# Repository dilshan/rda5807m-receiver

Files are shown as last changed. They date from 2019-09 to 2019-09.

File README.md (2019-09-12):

# FM stereo radio receiver with RDS

This tuner circuit is a quick prototype which I build to test the *RDA5807M* FM radio tuner IC. *RDA5807M* is a single-chip tuner IC with RDS and MPX decoder, and it equipped with I2C interface for control. 

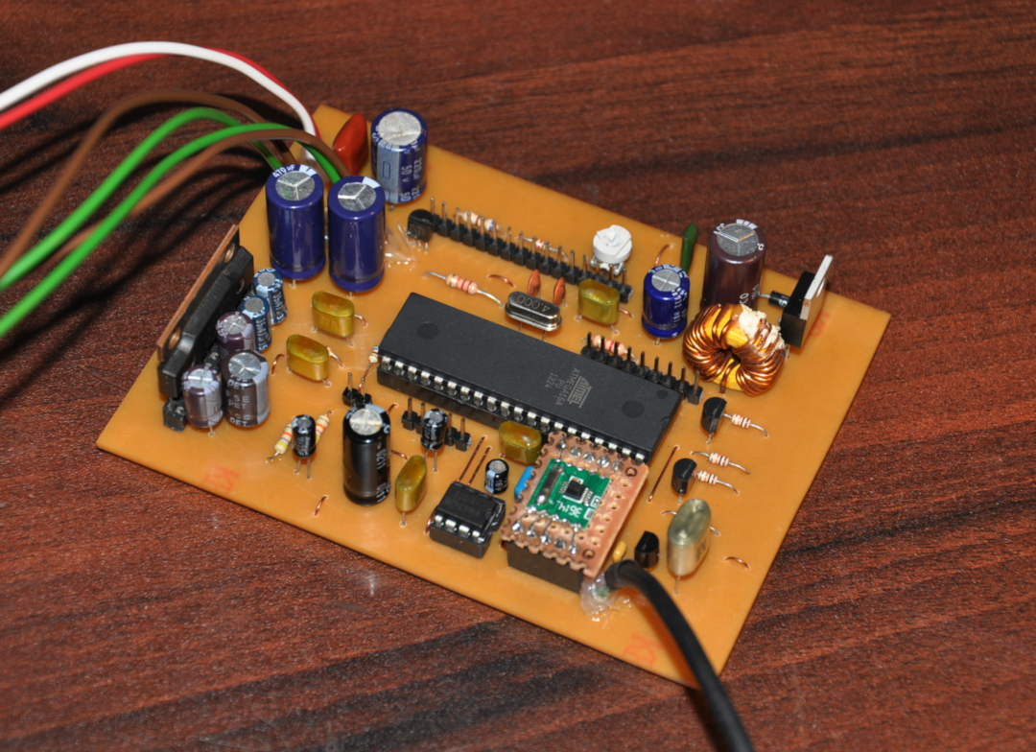
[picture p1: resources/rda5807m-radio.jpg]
Prototype version of the RDA5807M receiver


This receiver builds around Atmel's *ATmega16A* 8-bit MCU. The output stage of this design consists of *AN7147N*, 2×5.3W audio power amplifier. 

Based on the specifications of the switching-regulator and power amplifier, this circuit can drive between 9V to 20V DC input. The most recommended working voltage for this receiver is 12V.

As mentioned above this design is a quick prototype to test the features of *RDA5807M* tuner. Most of the parameters of this tuner are hardcoded in the firmware and not exposed in UI. 

-------------------------------------------------------------------------------------------------------------------------

The firmware source codes of this project are released under the terms of the [MIT license](https://github.com/dilshan/rda5807m-receiver/blob/master/LICENSE). All the design files and schematics are released under the terms of the [Creative Commons - Attribution 4.0 International license](https://creativecommons.org/licenses/by/4.0/).

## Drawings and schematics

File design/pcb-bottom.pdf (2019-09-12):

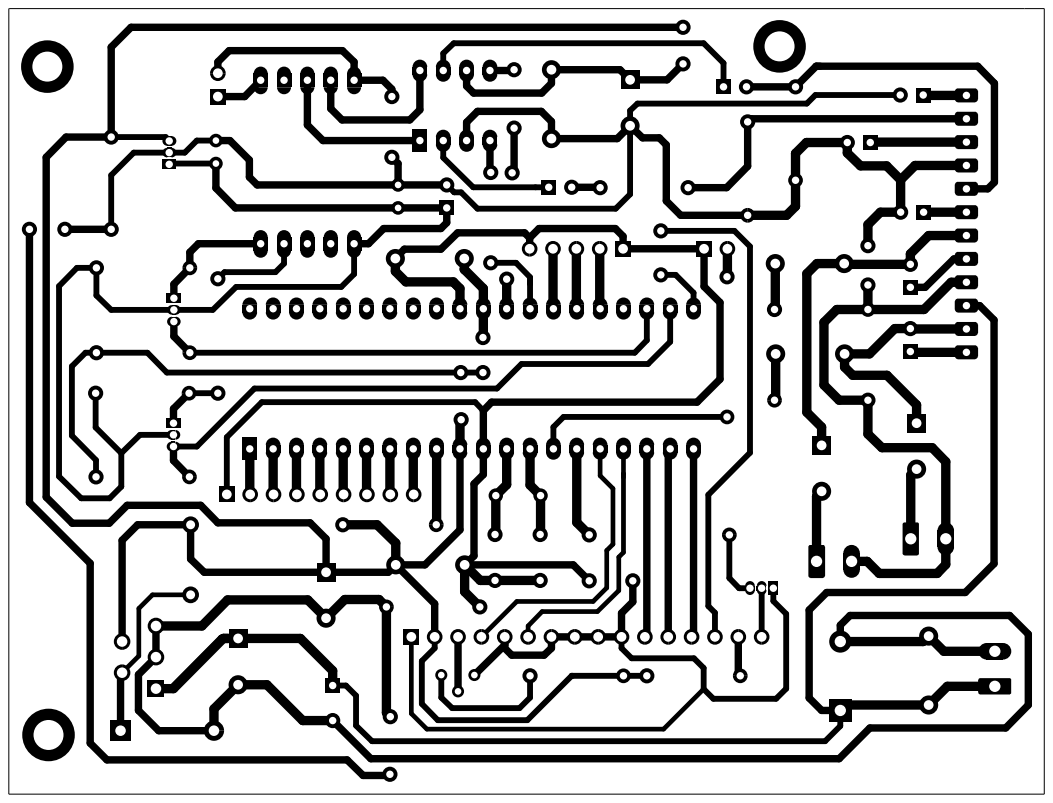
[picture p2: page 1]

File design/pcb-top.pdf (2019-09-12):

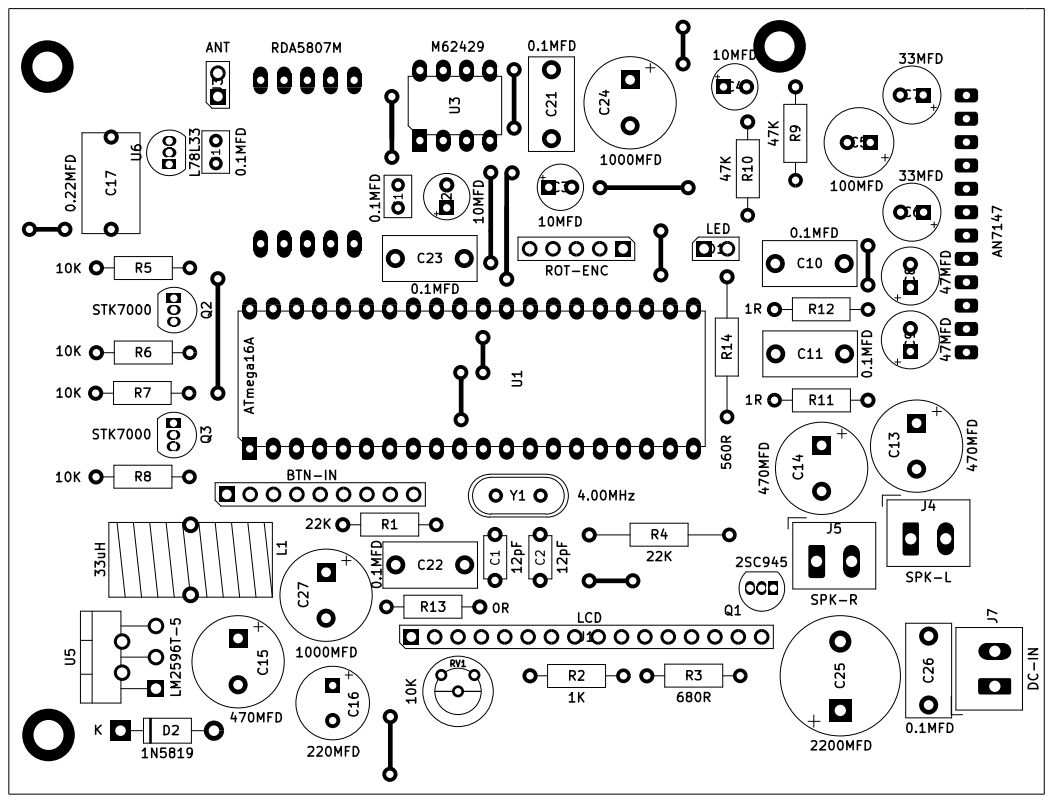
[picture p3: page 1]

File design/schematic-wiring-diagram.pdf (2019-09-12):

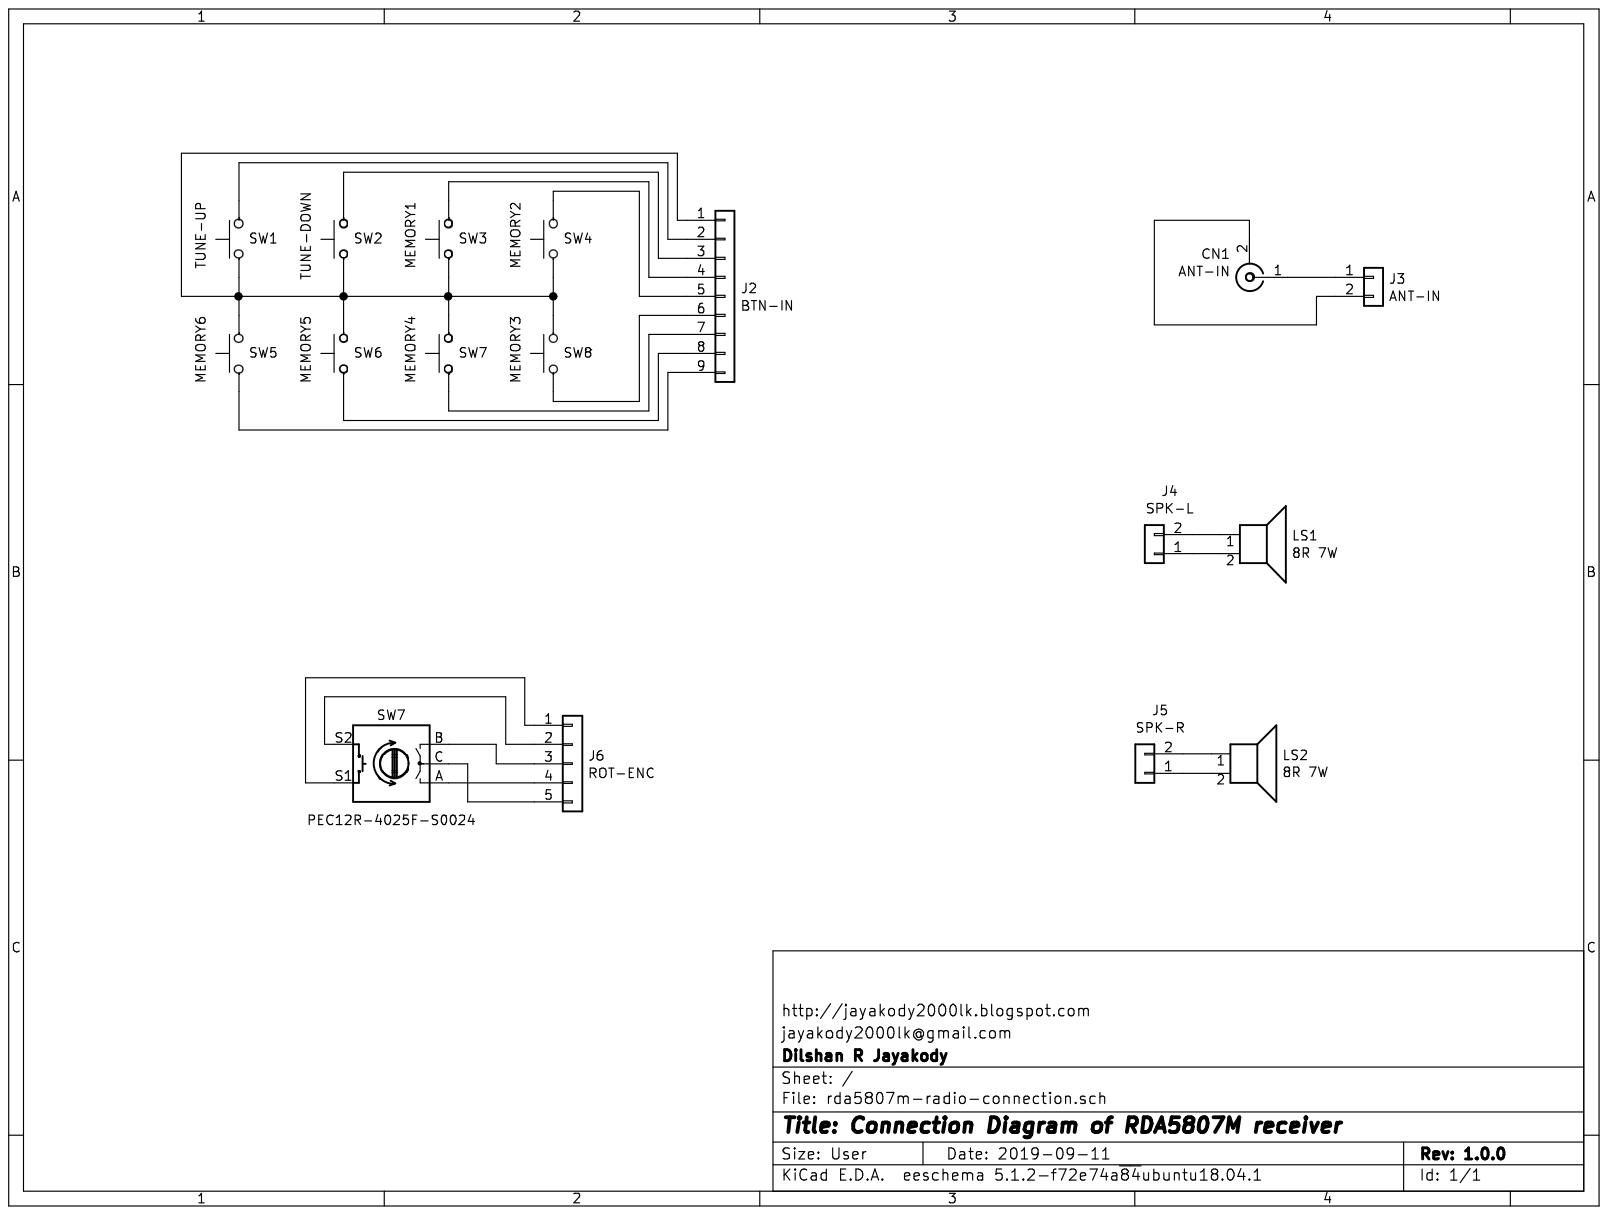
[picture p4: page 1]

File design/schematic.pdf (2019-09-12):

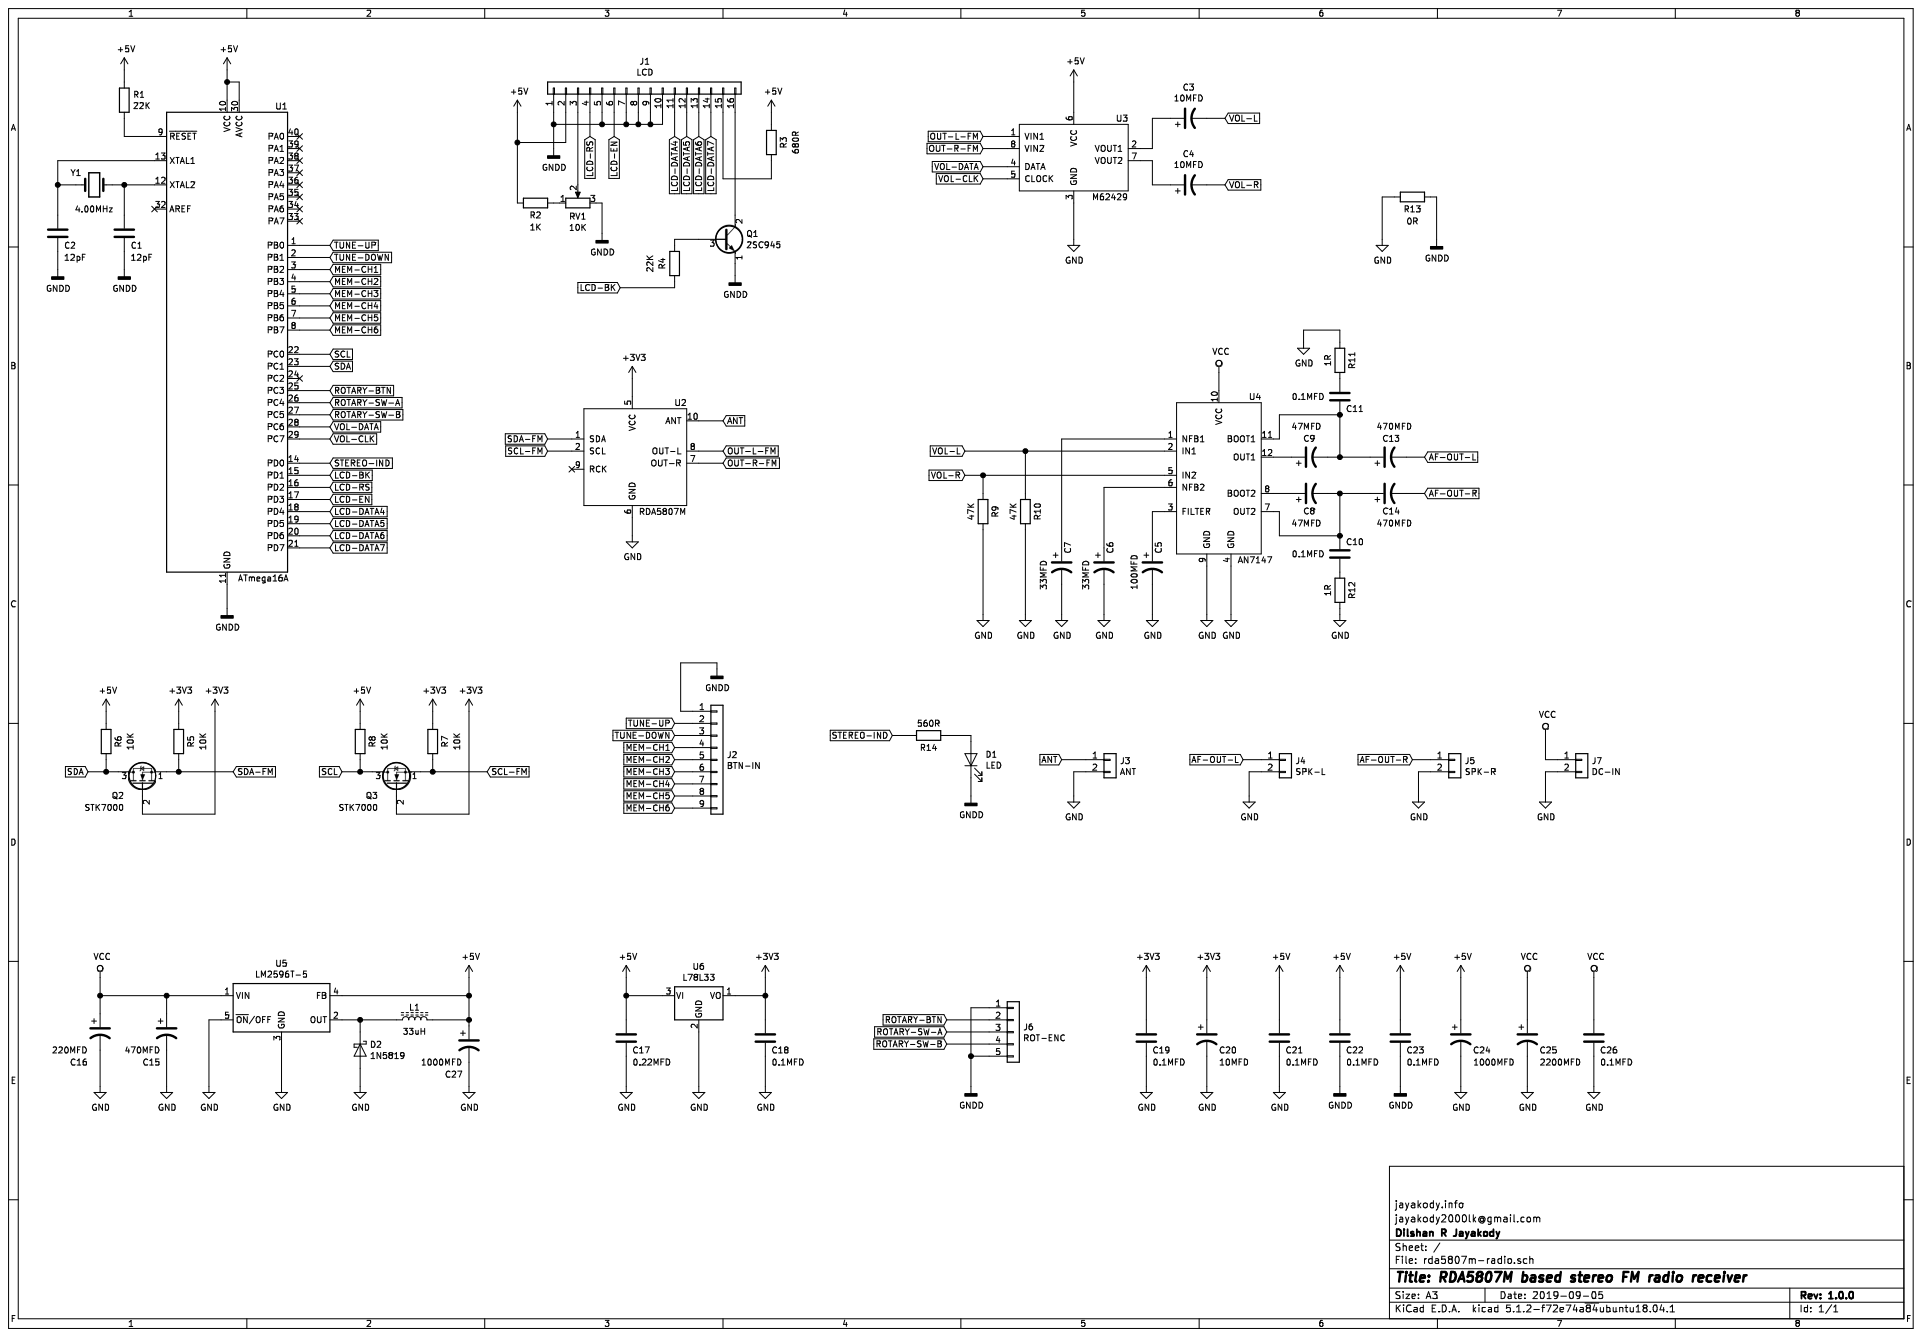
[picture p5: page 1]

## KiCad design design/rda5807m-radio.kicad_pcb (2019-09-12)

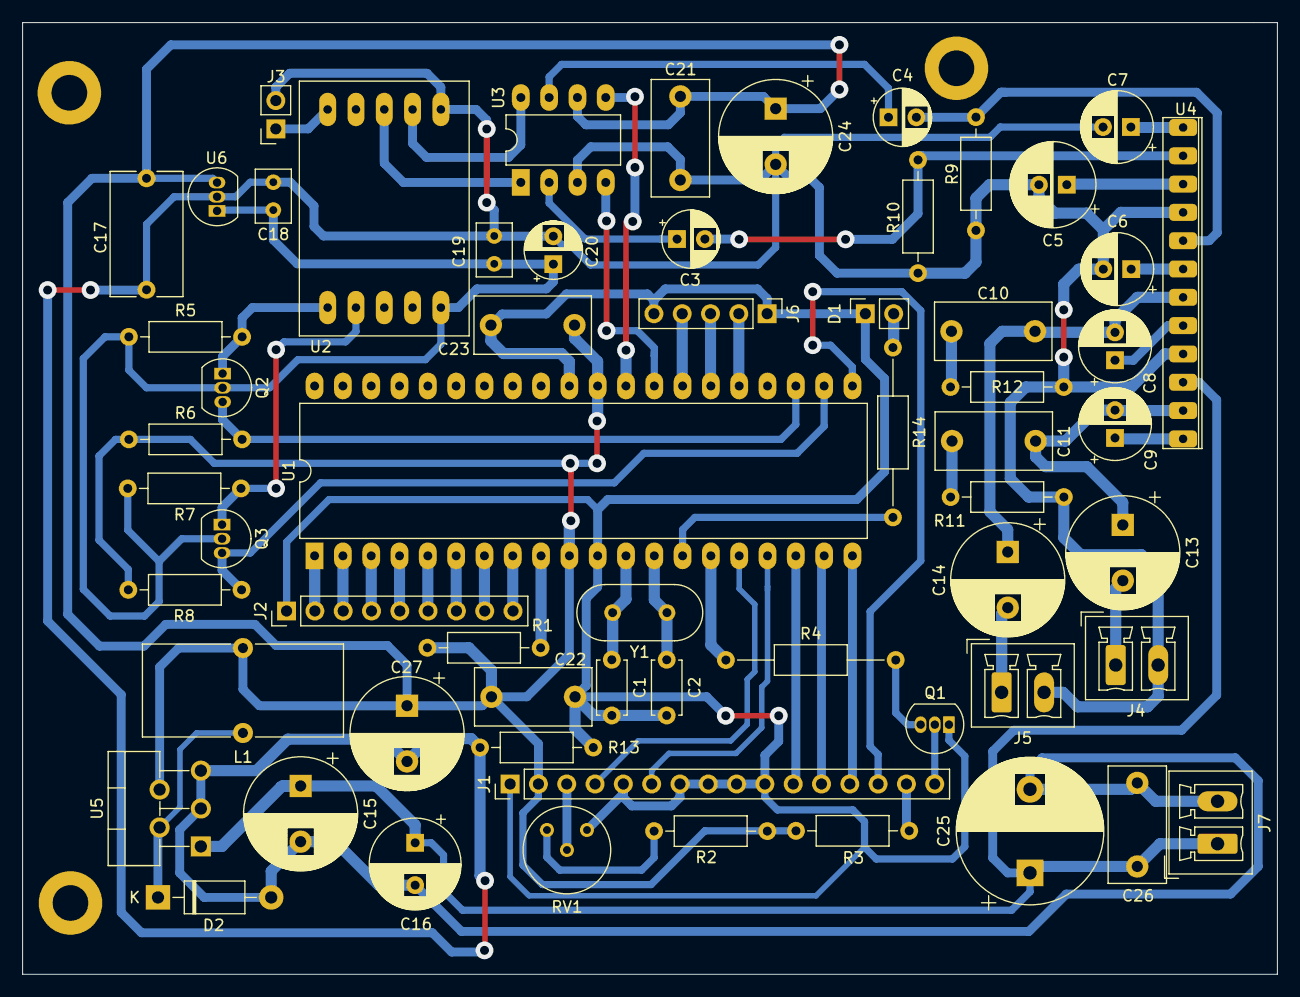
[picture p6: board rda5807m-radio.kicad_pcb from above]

Board: 2 copper layers, 112.6 x 85.4 mm, 64 parts (0 on the bottom side), 58 nets.

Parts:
 : MountingHole_3.2mm_M3_ISO7380_Pad
 #2,  #3: MountingHole_3.2mm_M3_ISO7380_Pad
C1, C2: 12pF; C_Disc_D4.7mm_W2.5mm_P5.00mm
C3, C4, C20: 10MFD; CP_Radial_D5.0mm_P2.50mm
C5: 100MFD; CP_Radial_D7.5mm_P2.50mm
C6, C7: 33MFD; CP_Radial_D6.3mm_P2.50mm
C8, C9: 47MFD; CP_Radial_D6.3mm_P2.50mm
C10, C11, C21, C22, C23, C26: 0.1MFD; C_Rect_L10.3mm_W5.0mm_P7.50mm_MKS4
C13, C14, C15: 470MFD; CP_Radial_D10.0mm_P5.00mm
C16: 220MFD; CP_Radial_D8.0mm_P3.80mm
C17: 0.22MFD; C_Rect_L11.0mm_W6.3mm_P10.00mm_MKT
C18, C19: 0.1MFD; C_Rect_L4.6mm_W3.0mm_P2.50mm_MKS02_FKP02
C24, C27: 1000MFD; CP_Radial_D10.0mm_P5.00mm
C25: 2200MFD; CP_Radial_D13.0mm_P7.50mm
D1: LED; PinSocket_1x02_P2.54mm_Vertical
D2: 1N5819; D_DO-41_SOD81_P10.16mm_Horizontal
J1: LCD; PinHeader_1x16_P2.54mm_Vertical
J2: BTN-IN; PinHeader_1x09_P2.54mm_Vertical
J3: ANT; PinSocket_1x02_P2.54mm_Vertical
J4: SPK-L; PhoenixContact_MCV_1,5_2-G-3.81_1x02_P3.81mm_Vertical
J5: SPK-R; PhoenixContact_MCV_1,5_2-G-3.81_1x02_P3.81mm_Vertical
J6: ROT-ENC; PinHeader_1x05_P2.54mm_Vertical
J7: DC-IN; PhoenixContact_MCV_1,5_2-G-3.81_1x02_P3.81mm_Vertical
L1: 33uH; L_Toroid_Vertical_L17.8mm_W8.1mm_P7.62mm_Bourns_5700
Q1: 2SC945; TO-92_Inline
Q2, Q3: STK7000; TO-92_Inline
R1: 22K; R_Axial_DIN0207_L6.3mm_D2.5mm_P10.16mm_Horizontal
R2: 1K; R_Axial_DIN0207_L6.3mm_D2.5mm_P10.16mm_Horizontal
R3: 680R; R_Axial_DIN0207_L6.3mm_D2.5mm_P10.16mm_Horizontal
R4: 22K; R_Axial_DIN0207_L6.3mm_D2.5mm_P15.24mm_Horizontal
R5, R6, R7, R8: 10K; R_Axial_DIN0207_L6.3mm_D2.5mm_P10.16mm_Horizontal
R9, R10: 47K; R_Axial_DIN0207_L6.3mm_D2.5mm_P10.16mm_Horizontal
R11, R12: 1R; R_Axial_DIN0207_L6.3mm_D2.5mm_P10.16mm_Horizontal
R13: 0R; R_Axial_DIN0207_L6.3mm_D2.5mm_P10.16mm_Horizontal
R14: 560R; R_Axial_DIN0207_L6.3mm_D2.5mm_P15.24mm_Horizontal
RV1: 10K; Potentiometer_Bourns_3339H_Vertical
U1: ATmega16A; DIP-40_W15.24mm_LongPads
U2: RDA5807M; RDA5807M-MODULE
U3: M62429; DIP-8_W7.62mm_LongPads
U4: AN7147; SIP-12-2P
U5: LM2596T-5; TO-220-5_P3.4x3.7mm_StaggerOdd_Lead3.8mm_Vertical
U6: L78L33; TO-92_Inline
Y1: 4.00MHz; Crystal_HC49-U_Vertical

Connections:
+3V3: C18.1, C19.1, C20.1, Q2.2, Q3.2, R5.1, R7.1, U2.5, U6.1
+5V: C17.1, C21.1, C22.1, C23.1, C24.1, C27.1, J1.2, L1.2, R1.1, R2.2, R3.1, R6.1, R8.1, U1.10, U1.30, U3.6, U5.4, U6.3
AF-OUT-L: C13.2, J4.1
AF-OUT-R: C14.2, J5.1
ANT: J3.1, U2.10
GND: C5.2, C6.2, C7.2, C15.2, C16.2, C17.2, C18.2, C19.2, C20.2, C21.2, C24.2, C25.2, C26.2, C27.2, D2.2, J3.2, J4.2, J5.2, J7.2, R9.2, R10.2, R11.1, R12.2, R13.2, U2.6, U3.3, U4.4, U4.9, U5.3, U5.5, U6.2
GNDD: C1.2, C2.2, C22.2, C23.2, D1.1, J1.1, J1.5, J1.7, J1.8, J1.9, J1.10, J2.1, J6.1, J6.5, Q1.1, R13.1, RV1.3, U1.11, U1.31
LCD-BK: R4.1, U1.15
LCD-DATA4: J1.11, U1.18
LCD-DATA5: J1.12, U1.19
LCD-DATA6: J1.13, U1.20
LCD-DATA7: J1.14, U1.21
LCD-EN: J1.6, U1.17
LCD-RS: J1.4, U1.16
MEM-CH1: J2.4, U1.3
MEM-CH2: J2.5, U1.4
MEM-CH3: J2.6, U1.5
MEM-CH4: J2.7, U1.6
MEM-CH5: J2.8, U1.7
MEM-CH6: J2.9, U1.8
unnamed: C1.1, U1.12, Y1.2
unnamed: C2.1, U1.13, Y1.1
unnamed: C3.1, U3.2
unnamed: C4.1, U3.7
unnamed: C5.1, U4.3
unnamed: C6.1, U4.6
unnamed: C7.1, U4.1
unnamed: C8.1, U4.8
unnamed: C9.1, U4.12
unnamed: C8.2, C10.1, C14.1, U4.7
unnamed: C10.2, R12.1
unnamed: C11.1, R11.2
unnamed: C9.2, C11.2, C13.1, U4.11
unnamed: D1.2, R14.1
unnamed: D2.1, L1.1, U5.2
unnamed: J1.3, RV1.2
unnamed: J1.15, R3.2
unnamed: J1.16, Q1.2
unnamed: Q1.3, R4.2
unnamed: R1.2, U1.9
unnamed: R2.1, RV1.1
OUT-L-FM: U2.8, U3.1
OUT-R-FM: U2.7, U3.8
ROTARY-BTN: J6.2, U1.25
ROTARY-SW-A: J6.3, U1.26
ROTARY-SW-B: J6.4, U1.27
SCL: Q3.3, R8.2, U1.22
SCL-FM: Q3.1, R7.2, U2.2
SDA: Q2.3, R6.2, U1.23
SDA-FM: Q2.1, R5.2, U2.1
STEREO-IND: R14.2, U1.14
TUNE-DOWN: J2.3, U1.2
TUNE-UP: J2.2, U1.1
VCC: C15.1, C16.1, C25.1, C26.1, J7.1, U4.10, U5.1
VOL-CLK: U1.29, U3.5
VOL-DATA: U1.28, U3.4
VOL-L: C3.2, R10.1, U4.2
VOL-R: C4.2, R9.1, U4.5

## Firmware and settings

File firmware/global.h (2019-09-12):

/*********************************************************************************
 * Copyright (c) 2019 Dilshan R Jayakody.
 * 
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
 * THE SOFTWARE IS PROVIDED "AS IS", WITHOUT WARRANTY OF ANY KIND, EXPRESS OR
 * IMPLIED, INCLUDING BUT NOT LIMITED TO THE WARRANTIES OF MERCHANTABILITY,
 * FITNESS FOR A PARTICULAR PURPOSE AND NONINFRINGEMENT. IN NO EVENT SHALL THE
 * AUTHORS OR COPYRIGHT HOLDERS BE LIABLE FOR ANY CLAIM, DAMAGES OR OTHER
 * LIABILITY, WHETHER IN AN ACTION OF CONTRACT, TORT OR OTHERWISE, ARISING FROM,
 * OUT OF OR IN CONNECTION WITH THE SOFTWARE OR THE USE OR OTHER DEALINGS IN THE
 * SOFTWARE.
 *********************************************************************************/

#ifndef GLOBAL_H_
#define GLOBAL_H_

// FUSE LOW  : 0x3F
// FUSE HIGH : 0xD9

// System clock is set to 4.00MHz.
#define F_CPU	4000000UL

// Default frequency is set to 87.00MHz.
#define DEFAULT_CHANNEL	52

// Default volume level is 0.
#define DEFAULT_VOLUME	0

// Idle limits for volume and tune controls.
#define IDLE_LIMIT_VOLUME	70
#define IDLE_LIMIT_TUNER	150

#define LONG_PRESS_COUNTS	15

typedef enum
{
	FALSE = 0x00,
	TRUE = 0xFF	
} BOOL;

typedef enum
{
	MA_NONE,
	MA_LOAD,
	MA_SAVE
} MEM_ACTION;

typedef struct
{
	unsigned char volume;
	unsigned short currentChannel;
} SYS_CONFIG;

#endif /* GLOBAL_H_ */

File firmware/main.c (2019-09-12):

/*********************************************************************************
 * Copyright (c) 2019 Dilshan R Jayakody.
 * 
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
 * THE SOFTWARE IS PROVIDED "AS IS", WITHOUT WARRANTY OF ANY KIND, EXPRESS OR
 * IMPLIED, INCLUDING BUT NOT LIMITED TO THE WARRANTIES OF MERCHANTABILITY,
 * FITNESS FOR A PARTICULAR PURPOSE AND NONINFRINGEMENT. IN NO EVENT SHALL THE
 * AUTHORS OR COPYRIGHT HOLDERS BE LIABLE FOR ANY CLAIM, DAMAGES OR OTHER
 * LIABILITY, WHETHER IN AN ACTION OF CONTRACT, TORT OR OTHERWISE, ARISING FROM,
 * OUT OF OR IN CONNECTION WITH THE SOFTWARE OR THE USE OR OTHER DEALINGS IN THE
 * SOFTWARE.
 *********************************************************************************/

#include "global.h"

#include <stdio.h>
#include <stdlib.h>
#include <string.h>
#include <avr/io.h>
#include <util/delay.h>
#include <avr/wdt.h>
#include <avr/interrupt.h>

#include "main.h"
#include "rda5807m.h"
#include "lcd.h"
#include "m62429.h"
#include "storage.h"

int main()
{
	SYS_STATE lastState;
	unsigned short memChannel;
	
	cli();
	
	initSystem();	
	setConfigDefault(&_currentConfig);
	
	// Setting up default values for the variables.
	_currentState = TUNER_IDLE;
	lastState = _currentState;
	_lastButtonState = PINB;
	_clearRDSinfo = FALSE;
	_needUpdateUI = FALSE;
	_updateSystemConfig = FALSE;
	_idleLimit = IDLE_LIMIT_VOLUME;
	_lastEncorderButtonVal = 0xFF;
	_memoryStoredFlag = 0;
	_memAction = MA_NONE;
	_defaultMemChannel = 0;

	memset(_lcdRow1, 0, LCD_MAX_ROW_LENGTH + 1);
	memset(_lcdRow2, 0, LCD_MAX_ROW_LENGTH + 1);
	
	memset(_memoryHoldCounter, 0, MEM_GROUP_SIZE);
	
	_delay_ms(1000);
	clearRDSData(_stationTempBuffer, _stationName, MAX_STATION_NAME_SIZE);
	
	initReceiver();
	_delay_ms(10);
	
	// Load and restore last system configuration.
	loadConfig(&_currentConfig);
	updateChannel(_currentConfig.currentChannel);
	_delay_ms(20);
	updateVolumeControl(_currentConfig.volume);
	_delay_ms(10);
	
	clearLCD();
	
	// Setup timer1 to generate interrupts with 100ms intervals.
	initButtonScanner();
	sei();
	
	// Enable watchdog timer with 2.1 seconds time configuration.
	wdt_enable(WDTO_1S);
	
	// Turn on LCD back-light when system is ready.
	PORTD |= 0x02;
	
	// Start main service loop.
	while(1)
	{
		// Reset watchdog timer.
		wdt_reset();
		
		if(_currentState == TUNER_IDLE)
		{
			// Handle tuner information processing and RDS routines.
			
			// Handle screen transitions.
			if(lastState != TUNER_IDLE)
			{
				clearLCD();
				lastState = TUNER_IDLE;
			}
			
			// Perform memory recall and save operations based on user actions.
			if(_memAction == MA_LOAD)
			{
				memChannel = loadMemorySlot(_defaultMemChannel);
				if(memChannel != _currentConfig.currentChannel)
				{
					updateChannel(memChannel);
					_clearRDSinfo = TRUE;
					_updateSystemConfig = TRUE;
				}
				
				_memAction = MA_NONE;
			}
			else if(_memAction == MA_SAVE)
			{
				if(saveMemoryStation(_defaultMemChannel, _currentConfig.currentChannel) == TRUE)
				{
					_memoryStoredFlag = 1;
				}
				
				_memAction = MA_NONE;
			}
			
			// Read status bits from receiver and extract tuner information.
			readConfiguration(_receiverInfo);
			extractFrequency(_receiverInfo[0], _lcdRow1);
			
			setCursor(1,1);
			printStr(_lcdRow1);
			
			// Handle RDS clear flag raised in ISR.
			if(_clearRDSinfo == TRUE)
			{
				// Clear current RDS data.
				clearRDSData(_stationTempBuffer, _stationName, MAX_STATION_NAME_SIZE);
				clearRow(2);
				
				_clearRDSinfo = FALSE;
				_delay_ms(25);
				continue;
			}
			
			// Update stereo indicator.
			PORTD &= 0xFE;
			if((_receiverInfo[0] & RDA5807_STEREO) != 0x00)
			{
				PORTD |= 0x01;
			}
			
			// Check current status of the tunning process.
			if((_receiverInfo[0] & RDA5807_SEEK_TUNE_COMPLETE) != 0)
			{
				// Extract RDS data if station is available.
				if((extractRDSData(_receiverInfo, _stationTempBuffer, _stationName) == TRUE) && (_memoryStoredFlag == 0))
				{
					setCursor(2, 1);
					memset(_lcdRow2, ' ', LCD_MAX_ROW_LENGTH);
					strcpy(_lcdRow2, _stationName);
					printStr(_lcdRow2);
				}
				
				// Update current channel information in EEPROM.
				if(_updateSystemConfig == TRUE)
				{
					_currentConfig.currentChannel = _receiverInfo[0] & RDA5807_CHANNEL_INFO;
					saveReceiverChannel(&_currentConfig);
				}
			}
			
			// Display "STORED" message during the channel preset.
			if(_memoryStoredFlag > 0)
			{
				setCursor(2, 1);
				printStr("STORED        ");
			}
			
			// Check for rotary encoder rotations.
			if((PINC & 0x30) != 0x30)
			{
				enterVolumeControl();
			}
						
			_delay_ms(20);
		}
		else if(_currentState == VOLUME_CONTROL)
		{
			// Handle rotary encoder related events
			_memAction = MA_NONE;
			
			// Handle screen transitions.
			if(lastState != VOLUME_CONTROL)
			{
				clearLCD();
				printStr("VOLUME: ");
				lastState = VOLUME_CONTROL;
			}
			
			// Check for rotary encoder rotations.
			if((PINC & 0x30) != 0x30)
			{
				if((!(PINC & 0x10)) && (_lastEncoderVal))
				{
					if(PINC & 0x20)
					{
						if(_rotaryEncoderPos < 100)
						{
							_rotaryEncoderPos++;
							_needUpdateUI = TRUE;
						}
					}
					else
					{
						if(_rotaryEncoderPos > 0)
						{
							_rotaryEncoderPos--;
							_needUpdateUI = TRUE;
						}
					}
				}
			}
			
			// Update volume information in both UI and controller.
			if(_needUpdateUI == TRUE)
			{
				// Draw new values into the screen
				sprintf(_lcdRow1, "%d  ", _rotaryEncoderPos);
				setCursor(1, 9);
				printStr(_lcdRow1);
				drawLevel(2, ((_rotaryEncoderPos * (LCD_MAX_ROW_LENGTH - 1)) / 100), FALSE);
				
				// Send volume information to the controller and EEPROM.
				updateVolumeControl(_rotaryEncoderPos);
				_currentConfig.volume = _rotaryEncoderPos;
				saveVolume(&_currentConfig);
				
				_idleCounter = 0;
				_needUpdateUI = FALSE;
			}
			
			_lastEncoderVal = (PINC & 0x10);
			_delay_us(750);
		}
		else if(_currentState == TUNER_CONTROL)
		{
			// Handle manual tunning.
			if(_indicatorCounter == 0)
			{
				readConfigurationFast(_receiverInfo);
							
				// Update stereo indicator.
				PORTD &= 0xFE;
				if((_receiverInfo[0] & RDA5807_STEREO) != 0x00)
				{
					PORTD |= 0x01;
				}	
			}
			
			_indicatorCounter++;
			
			// Handle screen transitions.
			if(lastState != TUNER_CONTROL)
			{
				clearLCD();
				lastState = TUNER_CONTROL;
			}
			
			// Check for rotary encoder rotations.
			if((PINC & 0x30) != 0x30)
			{
				if((!(PINC & 0x10)) && (_lastEncoderVal))
				{
					if(PINC & 0x20)
					{
						if(_rotaryEncoderPos < 210)
						{
							updateChannel(++_rotaryEncoderPos);
							_needUpdateUI = TRUE;
						}
					}
					else
					{
						if(_rotaryEncoderPos > 0)
						{
							updateChannel(--_rotaryEncoderPos);
							_needUpdateUI = TRUE;
						}
					}
				}
			}
			
		
			// Update current tuner information in the screen.
			if(_needUpdateUI == TRUE)
			{
				extractFrequency(_rotaryEncoderPos, _lcdRow1);
				
				setCursor(1,1);
				printStr(_lcdRow1);
				drawLevel(2, ((_rotaryEncoderPos * (LCD_MAX_ROW_LENGTH - 1)) / 210), TRUE);

				_idleCounter = 0;
				_needUpdateUI = FALSE;
			}

			_lastEncoderVal = (PINC & 0x10);
			_delay_us(100);
		}
	}
	
	return 0;
}

ISR (TIMER1_COMPA_vect)
{
	unsigned char memPos;
	
	// Reset watchdog timer.
	wdt_reset();
	
	// Reset memory stored flag after nearly 1 seconds.
	if(_memoryStoredFlag > 0)
	{
		if((++_memoryStoredFlag) > 11)
		{
			_memoryStoredFlag = 0;
		}
	}
	
	// Handle tuner related user events.
	if(_currentState == TUNER_IDLE)
	{
		// Check for TUNE UP button event.
		if(((_lastButtonState & BUTTON_TUNE_UP) == 0x00) && ((PINB & BUTTON_TUNE_UP) == BUTTON_TUNE_UP))
		{
			startSeek(SKMODE_UP);
			_clearRDSinfo = TRUE;
			_updateSystemConfig = TRUE;
		}
		
		// Check for TUNE DOWN button event.
		if(((_lastButtonState & BUTTON_TUNE_DOWN) == 0x00) && ((PINB & BUTTON_TUNE_DOWN) == BUTTON_TUNE_DOWN))
		{
			startSeek(SKMODE_DOWN);
			_clearRDSinfo = TRUE;
			_updateSystemConfig = TRUE;
		}
		
		// Check for rotary button press event.
		if(((_lastEncorderButtonVal & ROTARY_BUTTON) == 0x00) && ((PINC & ROTARY_BUTTON) == ROTARY_BUTTON))
		{
			enterTunerControl();
			return;
		}
	
		// Check for memory recall action.
		for(memPos = 0; memPos < MEM_GROUP_SIZE; memPos++)
		{
			// Count hold down times of the memory buttons.
			if(((PINB & _memoryButtonGroup[memPos]) == 0x00) && (_memoryHoldCounter[memPos] < 0xFF))
			{
				_memoryHoldCounter[memPos]++;
			}
			
			// Check for hold down timeout to store the current channel.
			if(_memoryHoldCounter[memPos] >= LONG_PRESS_COUNTS)
			{
				_memoryHoldCounter[memPos] = 0;
				_defaultMemChannel = memPos;
				_memAction = MA_SAVE;
				return;
			}
			
			// On normal button action load programmed channel from memory.
			if(((_lastButtonState & _memoryButtonGroup[memPos]) == 0x00) && ((PINB & _memoryButtonGroup[memPos]) == _memoryButtonGroup[memPos]))
			{
				_defaultMemChannel = memPos;
				_memAction = MA_LOAD;
				_memoryHoldCounter[memPos] = 0;
			}
			
			// Reset memory hold down counter on idle state.
			if((PINB & _memoryButtonGroup[memPos])	== _memoryButtonGroup[memPos])
			{
				_memoryHoldCounter[memPos] = 0;	
			}	
		}
				
		_lastButtonState = PINB;
	}
	else if((_currentState == VOLUME_CONTROL) || (_currentState == TUNER_CONTROL))
	{
		unsigned char idleTimeout;
		
		if(_idleCounter < 0xFF)
		{
			_idleCounter++;
		}
		
		idleTimeout = ((_idleCounter >= _idleLimit) && ((PINC & 0x30) == 0x30));

		if(idleTimeout || ((PINB & 0xFF) != 0xFF))
		{
			// Sub system time-out. Switch UI to the default (tuner).
			exitSubSystem();
		}
		
		if(((_lastEncorderButtonVal & ROTARY_BUTTON) == 0x00) && ((PINC & ROTARY_BUTTON) == ROTARY_BUTTON))
		{
			// Check for rotary button press event.
			if(_currentState == VOLUME_CONTROL)
			{
				enterTunerControl();
			}
			else
			{
				enterVolumeControl();
			}
			
			return;
		}
	}
	
	_lastEncorderButtonVal = PINC;
}

void enterVolumeControl()
{
	_rotaryEncoderPos = _currentConfig.volume;
	_idleCounter = 0;
	_idleLimit = IDLE_LIMIT_VOLUME;
	_lastEncoderVal = (PINC & 0x10);
	_lastEncorderButtonVal = 0xFF;
	_needUpdateUI = TRUE;
	_currentState = VOLUME_CONTROL;
}

void enterTunerControl()
{
	PORTD &= 0xFE;
	_rotaryEncoderPos = _currentConfig.currentChannel;
	_idleCounter = 0;
	_indicatorCounter = 0;
	_idleLimit = IDLE_LIMIT_TUNER;
	_lastEncoderVal = (PINC & 0x10);
	_lastEncorderButtonVal = 0xFF;
	_needUpdateUI = TRUE;
	_currentState = TUNER_CONTROL;
}

void exitSubSystem()
{
	if(_currentState == TUNER_CONTROL)
	{
		_clearRDSinfo = (_rotaryEncoderPos != _currentConfig.currentChannel) ? TRUE : FALSE;
		_currentConfig.currentChannel = _rotaryEncoderPos;
		
		// Save channel only on exit from manual tunning.
		saveReceiverChannel(&_currentConfig);
	}
	
	_idleCounter = 0;
	_lastButtonState = 0xFF;
	_needUpdateUI = FALSE;
	_currentState = TUNER_IDLE;
}

void setConfigDefault(SYS_CONFIG *config)
{
	config->volume = DEFAULT_VOLUME;
	config->currentChannel = DEFAULT_CHANNEL;
}

void initButtonScanner()
{
	TCNT1 = 0x00;
	TCCR1A = 0x00;
	TCCR1B = 0x0A;
	OCR1AH = 0xC3;
	OCR1AL = 0x4F;
	TIMSK = (1 << OCIE1A);
}

void initSystem()
{
	// Setup system registers.
	SFIOR = 0x00;
	
	// Disable UART and all it's I/O pins.
	UCSRB = 0x00;
	UCSRA = 0x00;

	// Setting up I/O ports.
	DDRD = 0xFF;
	PORTD = 0x00;
	DDRB = 0x00;
	PORTB = 0xFF;
	DDRC = 0xC0;
	PORTC = 0x3F;
		
	// Initialize libraries and sub-systems.
	updateVolumeControl(0);
	
	initLCD();
	clearLCD();
	
	_delay_ms(20);
}

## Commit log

2019-09-12 Initial version of design files and firmware source files.
    [rda5807m-radio-connection.sch, rda5807m-radio.kicad_pcb, rda5807m-radio.sch]
2019-09-12 Link prototype image with readme file.
